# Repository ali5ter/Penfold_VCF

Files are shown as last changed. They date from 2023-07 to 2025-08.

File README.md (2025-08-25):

> **⚠️ Archived 2025-08-25. No longer maintained.**

# Penfold_VCF
[KiCad](https://www.kicad.org/) project for the circuit and PCB of R.A. Penfolds VCF design which I adapted as a Eurorack powered module.
The original circuit is taken from [the book, "Electronic Synthesiser Construction" by R. A. Penfold](https://sdiy.info/wiki/Penfold_synthesiser), published by Babani in 1986.

I have kept to the original design as much as possible, but added power and switched INT.CV via [a Eurorack spec bus](https://doepfer.de/home_e.htm).

The circuit and PCB are verfied to work and being used as part of my modular build.

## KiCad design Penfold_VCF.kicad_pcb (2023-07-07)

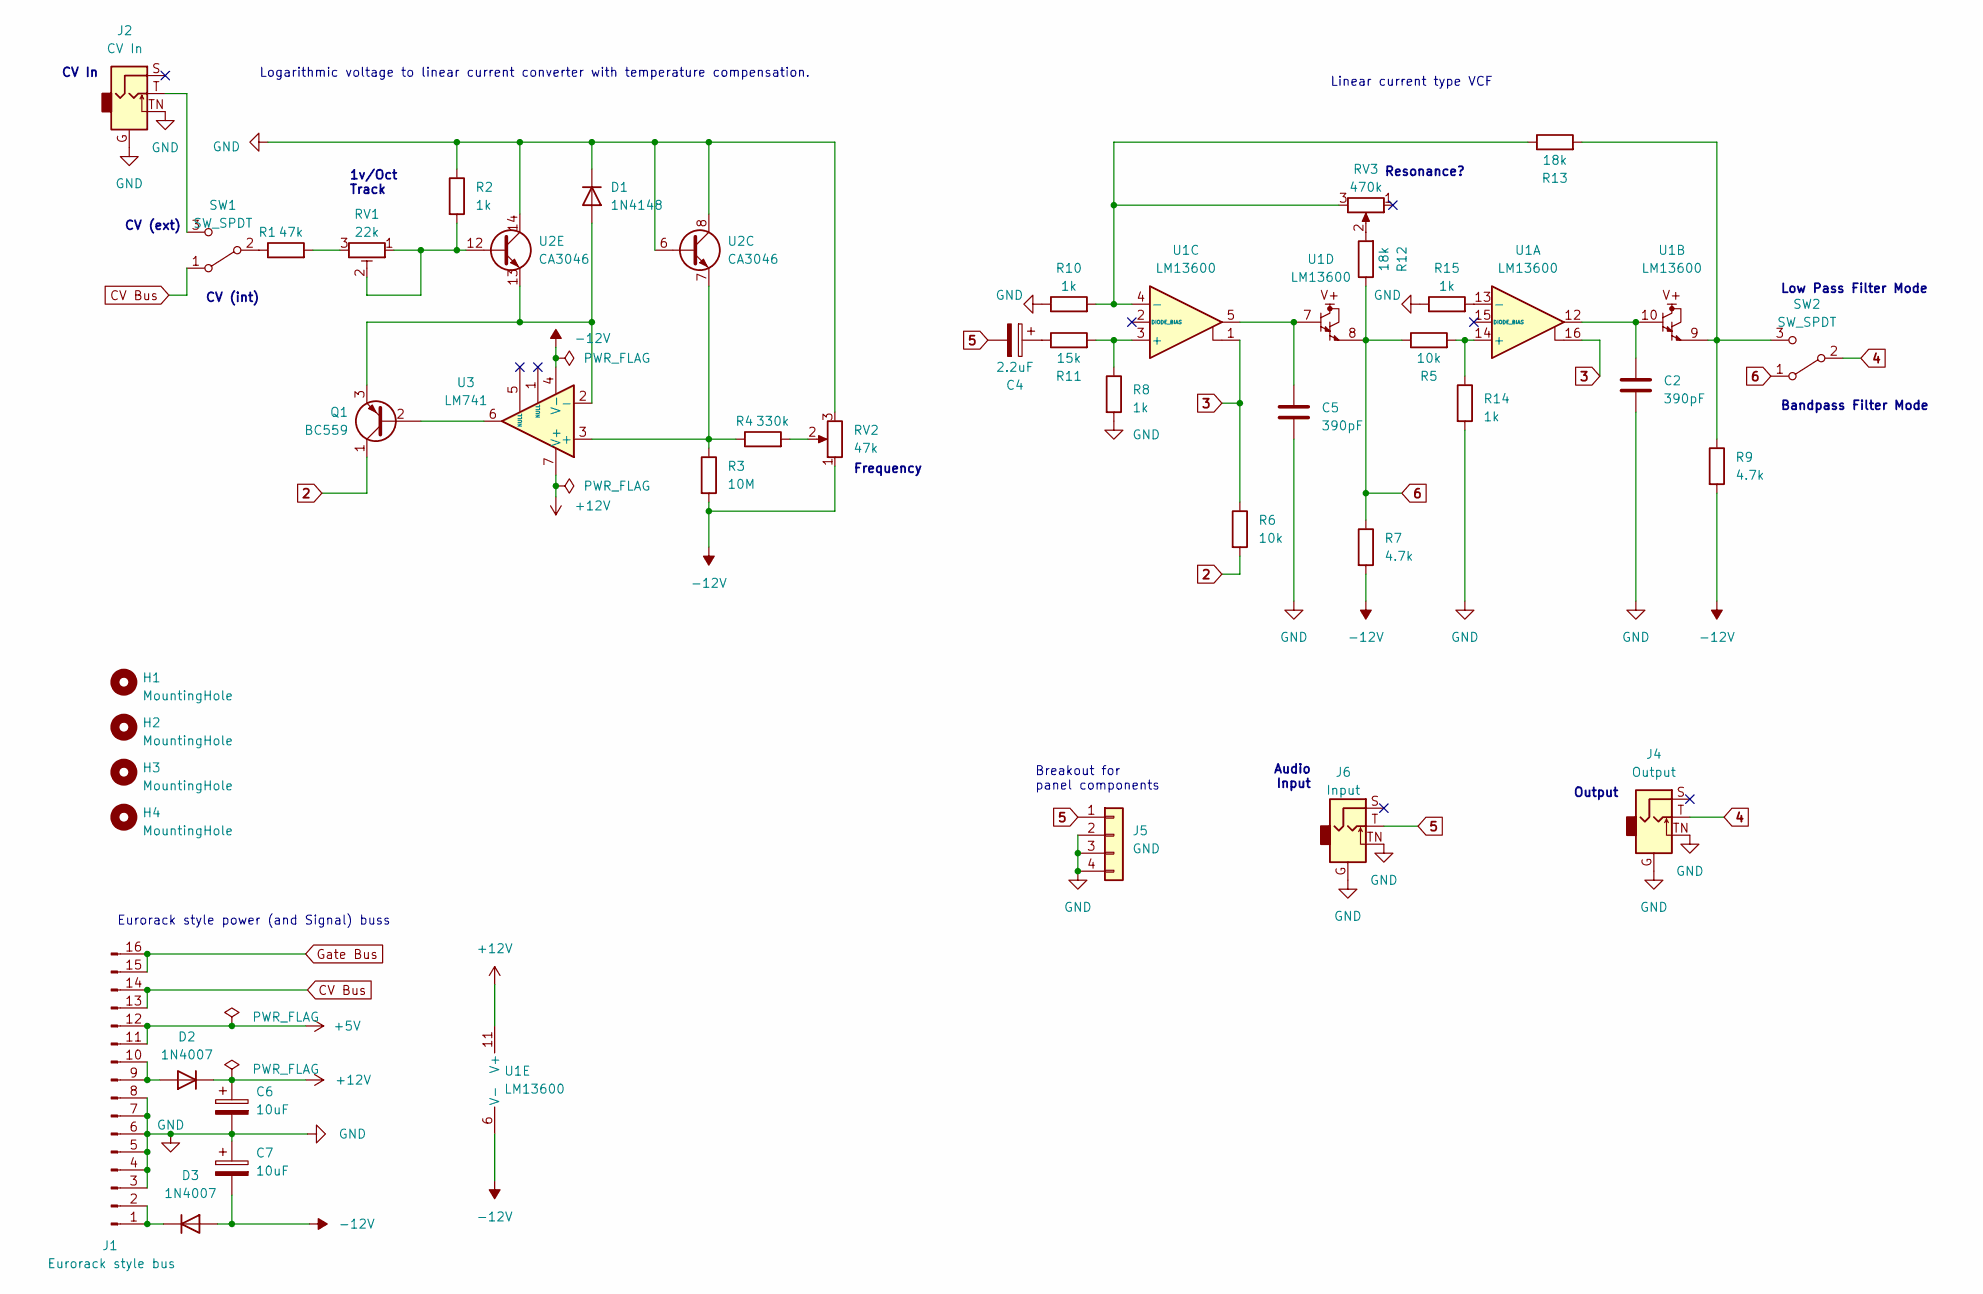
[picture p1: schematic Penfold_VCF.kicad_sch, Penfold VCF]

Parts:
C2, C5: 390pF; C_Disc_D5.0mm_W2.5mm_P5.00mm
C4: 2.2uF; CP_Radial_D5.0mm_P2.00mm
C6, C7: 10uF; CP_Radial_D5.0mm_P2.00mm
D1: 1N4148; D_DO-35_SOD27_P7.62mm_Horizontal
D2, D3: 1N4007; D_DO-41_SOD81_P10.16mm_Horizontal
H1, H2, H4: MountingHole; MountingHole_3.2mm_M3
H3: MountingHole; MountingHole_3mm
J1: Eurorack style bus; PinHeader_2x08_P2.54mm_Vertical
J2: CV In
J4: Output
J5: GND; PinHeader_1x04_P2.54mm_Vertical
J6: Input
Q1: BC559; TO-92_Inline
R1: 47k; R_Axial_DIN0207_L6.3mm_D2.5mm_P10.16mm_Horizontal
R2, R8, R10, R14, R15: 1k; R_Axial_DIN0207_L6.3mm_D2.5mm_P10.16mm_Horizontal
R3: 10M; R_Axial_DIN0207_L6.3mm_D2.5mm_P10.16mm_Horizontal
R4: 330k; R_Axial_DIN0207_L6.3mm_D2.5mm_P10.16mm_Horizontal
R5, R6: 10k; R_Axial_DIN0207_L6.3mm_D2.5mm_P10.16mm_Horizontal
R7, R9: 4.7k; R_Axial_DIN0207_L6.3mm_D2.5mm_P10.16mm_Horizontal
R11: 15k; R_Axial_DIN0207_L6.3mm_D2.5mm_P10.16mm_Horizontal
R12, R13: 18k; R_Axial_DIN0207_L6.3mm_D2.5mm_P10.16mm_Horizontal
RV1: 22k; PinHeader_1x03_P2.54mm_Vertical
RV2: 47k; PinHeader_1x03_P2.54mm_Vertical
RV3: 470k; PinHeader_1x03_P2.54mm_Vertical
SW1, SW2: SW_SPDT; PinHeader_1x03_P2.54mm_Vertical
U1: LM13600; DIP-16_W7.62mm_Socket_LongPads
U2: CA3046; DIP-14_W7.62mm_Socket
U3: LM741; DIP-8_W7.62mm_Socket_LongPads

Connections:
2: Q1.1 (C), R6.2
3: R6.1, U1.1, U1.16
4: J4.T, SW2.2 (B)
5: C4.2, J5.1, J6.T
6: R5.1, R7.1, R12.1, SW2.1 (A), U1.8
+5V: J1.11, J1.12
+12V: C6.1, D2.1 (K), U1.11 (V+), U3.7 (V+)
-12V: C7.2, D3.2 (A), R3.2, R7.2, R9.2, RV2.1, U1.6 (V-), U3.4 (V-)
CV Bus: J1.13, J1.14, SW1.1 (A)
GND: C2.2, C5.2, C6.2, C7.1, D1.1 (K), J1.3, J1.4, J1.5, J1.6, J1.7, J1.8, J2.G, J2.TN, J4.G, J4.TN, J5.2, J5.3, J5.4, J6.G, J6.TN, R2.1, R8.2, R10.1, R14.2, R15.1, RV2.3, U2.6 (B3), U2.8 (C3), U2.14 (C5)
Gate Bus: J1.15, J1.16
unnamed: C2.1, U1.10, U1.12
unnamed: C4.1, R11.1
unnamed: C5.1, U1.5, U1.7
unnamed: D1.2 (A), Q1.3 (E), U2.13 (E5), U3.2 (-)
unnamed: D2.2 (A), J1.9, J1.10
unnamed: D3.1 (K), J1.1, J1.2
unnamed: Q1.2 (B), U3.6
unnamed: R1.2, RV1.3
unnamed: R4.2, RV2.2
unnamed: R12.2, RV3.2
unnamed: R1.1, SW1.2 (B)
unnamed: J2.T, SW1.3 (C)
unnamed: R9.1, R13.2, SW2.3 (C), U1.9
unnamed: R5.2, R14.1, U1.14 (+)
unnamed: R15.2, U1.13 (-)
unnamed: R8.1, R11.2, U1.3 (+)
unnamed: R10.2, R13.1, RV3.3, U1.4 (-)
unnamed: R3.1, R4.1, U2.7 (E3), U3.3 (+)
unnamed: R2.2, RV1.1, RV1.2, U2.12 (B5)

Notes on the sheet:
CV In
Linear current type VCF
CV (ext)
Eurorack style power (and Signal) buss
CV (int)
Low Pass Filter Mode
Output
Frequency
Resonance?
Breakout for panel components
Logarithmic voltage to linear current converter with temperature compensation.
Audio Input
Bandpass Filter Mode
1v/Oct Track

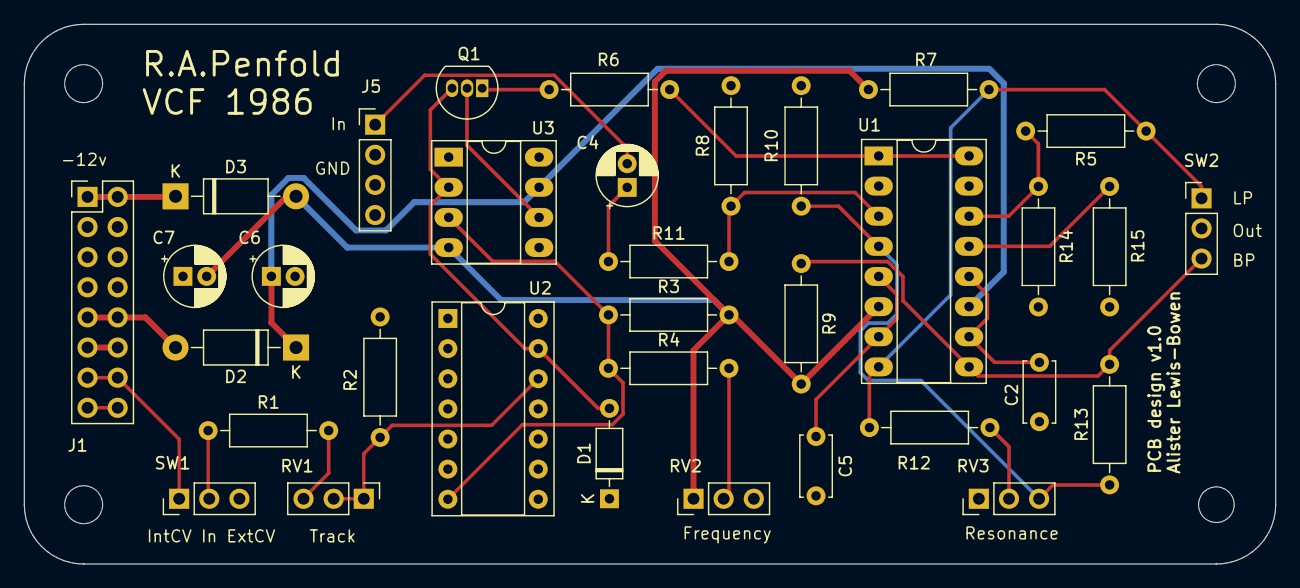
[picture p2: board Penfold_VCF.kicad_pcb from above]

Board: 2 copper layers, 105.5 x 45.5 mm, 38 parts (0 on the bottom side), 28 nets.
